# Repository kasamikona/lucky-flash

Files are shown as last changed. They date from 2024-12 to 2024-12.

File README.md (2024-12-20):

# Lucky Guitar Flashcart
A custom flashcart for the Lucky Group electronic guitar toy (らっき組 ギター) RK-001, made by People Co., Ltd.  

## What's it for?
The guitar toy, which I will call the Lucky Guitar from here onwards, has multiple play modes.
One of these modes uses ROM cartridges containing songs which you can play along with.
The songs are stored as MIDI files containing chord information.  

There were 14 main cartridges made, focusing on certain genres or artists,
and an additional "demo" cartridge containing a compilation of songs from the others.
The Lucky Guitar came with 2 or 3 random cartridges in the box, though additional ones could be purchased.
As it was a relatively obscure device, the cartridges are quite rare and it is very hard to collect them all.  

To allow the Lucky Guitar to be enjoyed to its fullest, I have developed a flash cart based heavily on the original cartridge design.
It supports playing ROM dumps of existing cartridges, as well as custom ROMs made from your own suitable MIDI files.
The latest version supports up to 8 different ROMs on one cartridge, with DIP switches to select them.  

Due to their small size, the flash carts contain no active logic and must be programmed externally.
Currently this is done through a custom adapter stackup for the TL866 (aka "MiniPro") Universal Programmer.
The stackup consists of a SN001-1 aka TSOP48 V3 base board from XinGong Tech, and the custom cartridge interface from here.
This adapter stack also allows dumping ROMs from the original cartridges after some modifications.  

## Contents
The main files you will want for making and using the flash cart are:
- **CartFlashMulti**: the latest multi-bank flash cart with DIP switches, intended for use with the custom shell. Gerber files coming soon.
- **LuckyCartInterface-TL866**: flash programmer interface for the TL866 and SN001-1. Gerber files coming soon.
- **CartShell.scad**: custom cart shell for the multi-bank flash cart, designed for SLA 3D printing. Render the main and cover parts separately. STL files coming soon.
- **CartParts.kicad_sym / CartParts.pretty**: custom KiCad parts shared between all PCBs.

The repo contains these additional files:
- **CartReplica**: a copy of the original cart PCB for research and analysis.
- **CartFlashSingle**: a flash cart based on the original carts, with minimal changes to support externally programming a flash chip. This can fit in an original shell.
- **DIP48-SN001**: a helper board that theoretically allows the cart interface to be used on other programming devices with 48-pin sockets.

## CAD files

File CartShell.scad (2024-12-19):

// Output settings
render_main = true;
render_cover = false;
prerender = true;
preview_print = true;

// Enhancements
enh_dipswitch = true;
enh_noholes = false;
enh_snapfit = true;
enh_post_supports = true;
enh_pegs_to_slots = true;
enh_label_top = true;

// Main dimensions
main_xsize = 68.8;
main_xslant = 0.3/20;
wall_xy = 1.5;
wall_z = 1.5;
wall_supp = 1.1;
wall_notch = 1.1;
curve_xc = 40.5;
curve_yc = -255;
curve_angle_start = 91;
curve_angle_range = 15.5;
profile_front = 46;
profile_handle_depth = profile_front-10;
profile_handle_slant = 0.12;
profile_handle_chamfer = 4.5;
main_height = 12.7;
handle_height = 15;

// Secondary dimensions
ridge_height = 1.5;
ridge_inset = 1.5;
label_height = 0.5;

// Screws & posts
screw_od = 2.0; //2.3
screwhead_od = 3.8;
screwpost_od = 4.0;
screw_shrink = 0.3;

// Clearances
clearance_lid = 0.3;
clearance_pcb = 0.2;
clearance_postxy = 0.2;
clearance_postz = 0.1;
clearance_screw = 0.1;
clearance_snap = 0.1;

// PCB parameters
pcb_thick = 1.2;
pcb_ypos = 0.5;
pcb_zpos = 5.7;
pcb_cardedge_width = 58;

// DIP switch dimensions
dip_n = 4;
dip_x = 23;
dip_y = 29;
dip_t = 3.6;
dip_angle = 90;
dip_w = 6.6;
dip_h = 2.54*dip_n + 1.2;
dip_rim_top = true;
dip_rim_bottom = false;
dip_rim_left = false;
dip_rim_right = true;

// Fixing positions
screws = [
    [-30,13.5], [30,13.5], [-30,32], [30,40]
];
snaps = [
    [-1, 10.5], [1, 10.5], [-1, 29], [1, 38]
];

// Calculated
detail = $preview ? 4 : 16;
below_pcb = pcb_zpos - clearance_pcb;
above_pcb = pcb_zpos + pcb_thick + clearance_pcb;
cover_zsize = below_pcb;
max_height = handle_height+ridge_height+1;
print_spacing = 5;
epsilon = 0.05;
screwhole_id = screwhead_od + 2*clearance_screw;

// Viewport centering
//$vpt = [0, profile_front/2, max_height/2];

module profile_curve(detail) {
    fnc = round(detail * 360 / curve_angle_range);
    translate([curve_xc,curve_yc,0])
    rotate([0,0,curve_angle_start])
    rotate_extrude(angle=curve_angle_range,
        convexity=5,$fn=fnc)
    translate([-curve_yc,0])
    children();
}

module main_profile(pocket, detail) {
    inset_xy = pocket ? wall_xy : 0;
    inset_z = pocket ? wall_z : 0;
    fdepth = profile_front-inset_xy;
    fslant = profile_handle_slant;
    tdepth = profile_handle_depth+inset_xy;
    fheight = handle_height-inset_z;
    theight = main_height-inset_z
        - (pocket ? label_height : 0);
    fcham = profile_handle_chamfer
        - max(inset_xy, inset_z);
    union() {
        hull() {
            polygon([
                [tdepth, 0], [fdepth, 0],
                [tdepth, fheight]
            ]);
            ch = fheight-fcham;
            sl = fslant*ch;
            translate([fdepth-sl-fcham, ch])
            intersection() {
                circle(r=fcham, $fn=detail*4);
                square(fcham+1);
            }
        }
        polygon([
            [0, 0], [tdepth+1, 0], 
            [tdepth+1, theight],
            [0, theight]
        ]);
    }
}

module side_profile(pocket, detail) {
    r1 = 1;
    h1 = main_height;
    h2 = handle_height;
    d1 = profile_front;
    slot_depth = 8;
    back = pocket ? slot_depth-epsilon : r1+1;
    union() {
        if(!pocket) hull() {
            polygon([
                [0, 0], [r1+2, 0],
                [r1+2, h1]
            ]);
            translate([r1, h1-r1])
            circle(r=r1, $fn=detail*4);
        }
        polygon([
            [back, 0], [d1, 0],
            [d1, h2], [back, h2]
        ]);
    }
}

module slant_profile(inset) {
    sp_height = max_height;
    x1 = main_xsize/2-inset;
    x2 = x1 - sp_height*main_xslant;
    polygon([
        [-x1, 0], [x1, 0],
        [x2, sp_height], [-x2, sp_height]
    ]);
}

module ridges(detail) {
    base = handle_height;
    sidegap = ridge_inset+(base*main_xslant);
    max_depth = profile_front;
    ridge_depth = 4;
    ridge_slant = 0.05;
    a = profile_handle_depth;
    b = a + ridge_depth*1/3;
    c = a + ridge_depth*2/3;
    d = a + ridge_depth;
    sl = ridge_slant * ridge_height;
    cx = main_xsize/2;
    intersection() {
        translate([-cx+sidegap, 0, 0])
        cube([main_xsize - 2*sidegap,
            max_depth, ridge_height+base]);
        profile_curve(detail*4){
            polygon([
                [a, 0],
                [b+sl, 0],
                [b+sl, base],
                [b, base+ridge_height],
                [a, base+ridge_height]
            ]);
            polygon([
                [c-sl, 0],
                [d, 0],
                [d, base+ridge_height],
                [c, base+ridge_height],
                [c-sl, base]
            ]);
        }
    }
}

module label(detail) {
    cheight = main_height;
    lheight = label_height;
    topgap = enh_label_top ? wall_xy : 0;
    bottomgap = wall_xy;
    sidegap = wall_xy+(cheight*main_xslant);
    cdepth = profile_handle_depth - topgap;
    lwidth = main_xsize-2*sidegap;
    cx = main_xsize/2;
    difference() {
        intersection() {
            profile_curve(detail*4) polygon([
                [0, cheight-lheight-1],
                [cdepth, cheight-lheight-1],
                [cdepth, cheight+1],
                [0, cheight+1]
            ]);
            translate([-cx+sidegap, bottomgap,
                cheight-lheight])
            cube([lwidth, cdepth+1,
                lheight+epsilon]);
        }
        if(enh_dipswitch) dip_hole(detail, true);
    }
}

module lock_notch(inset) {
    case_xsize = main_xsize/2-inset;
    xsize = 3;
    ysize = 8 + inset*1.41;
    zsize = main_height - wall_z;
    slant = 0.01 * zsize;
    ypos = 27.5-inset;
    translate([case_xsize,ypos,-epsilon])
    hull() {
        linear_extrude(epsilon)
        polygon([
            [-xsize, 0],
            [epsilon, 0],
            [epsilon, ysize+slant+epsilon],
            [-xsize, ysize+slant-xsize]
        ]);
        translate([0,0,zsize])
        linear_extrude(epsilon)
        polygon([
            [-xsize, 0],
            [epsilon, 0],
            [epsilon, ysize+epsilon],
            [-xsize, ysize-xsize]
        ]);
    }
}

module slot_cutout() {
    inset = wall_xy;
    height = main_height-wall_z;
    cutout_width = main_xsize-2*inset;
    depth = 8+epsilon;
    cx = main_xsize/2;
    translate([inset-cx,-epsilon,-epsilon])
    cube([cutout_width, depth+epsilon, height]);
}

module dip_hole(detail, negative) {
    max_side = 100;
    rim_radius = 1.0;
    c_w = dip_w +
        (negative ? rim_radius*2 : 0);
    c_h = dip_h +
        (negative ? rim_radius*2 : 0);
    corner_radius = negative ? rim_radius : 0.25;
    shrink = negative ? 0 : corner_radius*2*0.5;
    fn = detail * (negative ? 4 : 2);
    translate([dip_x, dip_y+pcb_ypos])
    minkowski() {
        rotate([0, 0, dip_angle])
        minkowski() {
            translate([0, 0, max_height/2])
            cube([c_w-shrink, c_h-shrink,
                max_height], true);
            if(corner_radius > 0)
            cylinder(r=corner_radius, h=1, $fn=fn);
        }
        if(negative) {
            rexx = dip_rim_left ? -max_side : 0;
            rexy = dip_rim_bottom ? -max_side : 0;
            rexw = (dip_rim_left ? max_side : 0)
                + (dip_rim_right ? max_side : 0)
                + 0.001;
            rexh = (dip_rim_top ? max_side : 0)
                + (dip_rim_bottom ? max_side : 0)
                + 0.001;
            translate([rexx, rexy, 0])
            cube([rexw, rexh, 1]);
        }
    }
}

module snapfit(indent) {
    extra_inset = indent ? clearance_snap : 0;
    snap_xsize = clearance_lid + 0.5;
    snap_zsizet = snap_xsize;
    snap_zsizeb = 1.5;
    snap_zpos = 2.0;
    snap_ysize = 2.0 + (indent ? 2*clearance_lid : 0);
    snap_inset = wall_xy + extra_inset;
    epsilon = 0.01;
    zeb = epsilon * snap_zsizeb/snap_xsize;
    zet = epsilon * snap_zsizet/snap_xsize;
    for(snap = snaps) {
        sxsign = -sign(snap[0]);
        sx = -main_xsize/2 + snap_inset;
        sy = snap[1];
        translate([sx*sxsign, sy, snap_zpos])
        rotate([90,0,0])
        linear_extrude(snap_ysize,
            center=true)
        polygon([
            [-epsilon*sxsign, -snap_zsizeb-zeb],
            [snap_xsize*sxsign, 0],
            [-epsilon*sxsign, snap_zsizet+zet]
        ]);
    }
}
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

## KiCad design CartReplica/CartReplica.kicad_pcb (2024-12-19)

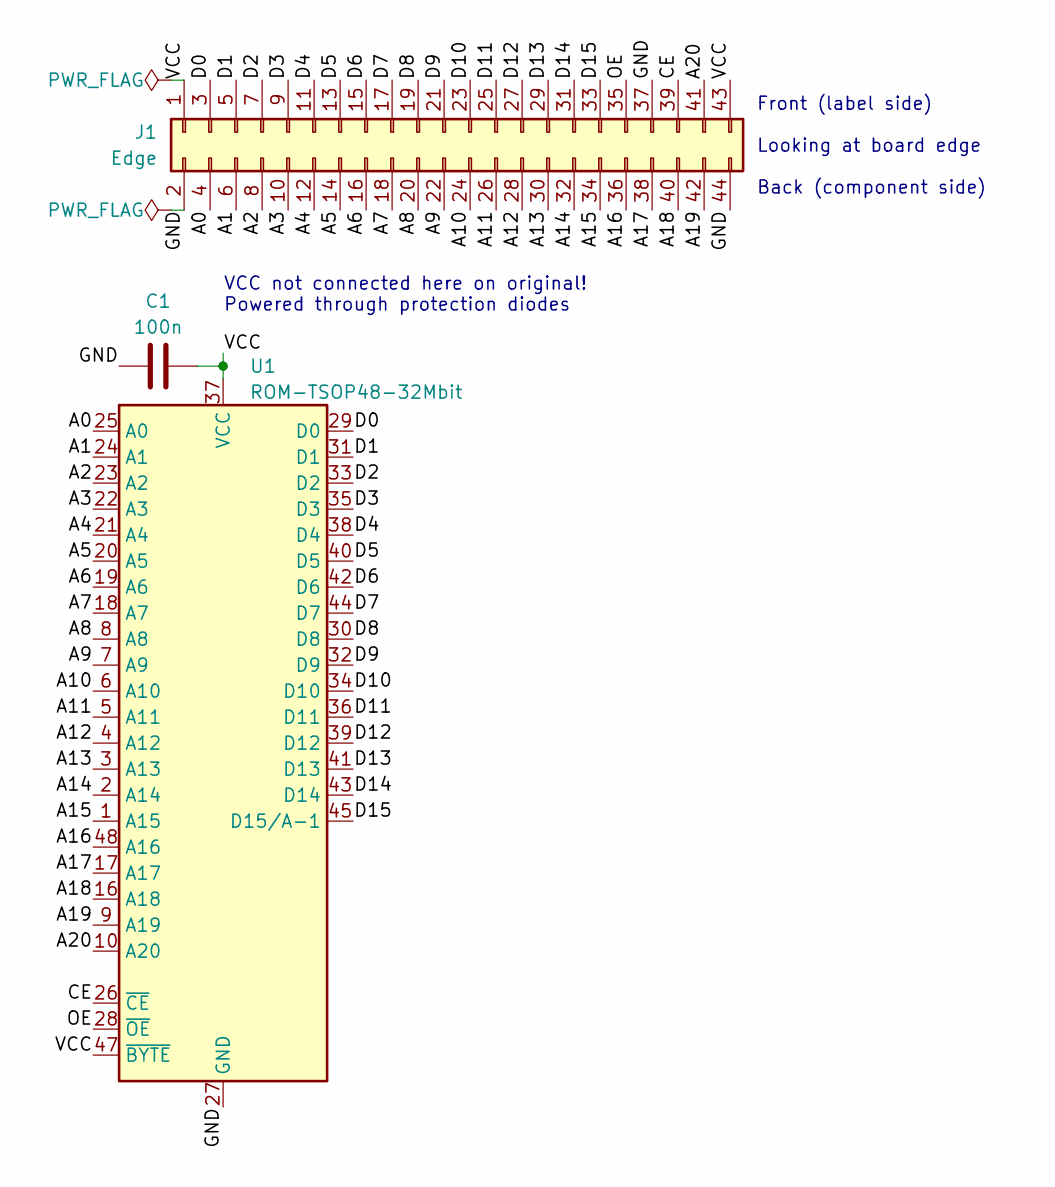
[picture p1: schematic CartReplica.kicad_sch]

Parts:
C1: 100n; C_0603_1608Metric_Pad1.08x0.95mm_HandSolder
J1: Edge; LuckyCartEdge
U1: ROM-TSOP48-32Mbit; TSOP-I-48_18.4x12mm_P0.5mm

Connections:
/A0: J1.4, U1.25 (A0)
/A1: J1.6, U1.24 (A1)
/A2: J1.8, U1.23 (A2)
/A3: J1.10, U1.22 (A3)
/A4: J1.12, U1.21 (A4)
/A5: J1.14, U1.20 (A5)
/A6: J1.16, U1.19 (A6)
/A7: J1.18, U1.18 (A7)
/A8: J1.20, U1.8 (A8)
/A9: J1.22, U1.7 (A9)
/A10: J1.24, U1.6 (A10)
/A11: J1.26, U1.5 (A11)
/A12: J1.28, U1.4 (A12)
/A13: J1.30, U1.3 (A13)
/A14: J1.32, U1.2 (A14)
/A15: J1.34, U1.1 (A15)
/A16: J1.36, U1.48 (A16)
/A17: J1.38, U1.17 (A17)
/A18: J1.40, U1.16 (A18)
/A19: J1.42, U1.9 (A19)
/A20: J1.41, U1.10 (A20)
/CE: J1.39, U1.26 (~CE)
/D0: J1.3, U1.29 (D0)
/D1: J1.5, U1.31 (D1)
/D2: J1.7, U1.33 (D2)
/D3: J1.9, U1.35 (D3)
/D4: J1.11, U1.38 (D4)
/D5: J1.13, U1.40 (D5)
/D6: J1.15, U1.42 (D6)
/D7: J1.17, U1.44 (D7)
/D8: J1.19, U1.30 (D8)
/D9: J1.21, U1.32 (D9)
/D10: J1.23, U1.34 (D10)
/D11: J1.25, U1.36 (D11)
/D12: J1.27, U1.39 (D12)
/D13: J1.29, U1.41 (D13)
/D14: J1.31, U1.43 (D14)
/D15: J1.33, U1.45 (D15/A-1)
/OE: J1.35, U1.28 (~OE)
/VCC: C1.1, J1.1, J1.43, U1.37 (VCC), U1.47 (~BYTE)
GND: C1.2, J1.2, J1.37, J1.44, U1.27 (GND), U1.46 (GND)

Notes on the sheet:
VCC not connected here on original! Powered through protection diodes
Front (label side) Looking at board edge Back (component side)

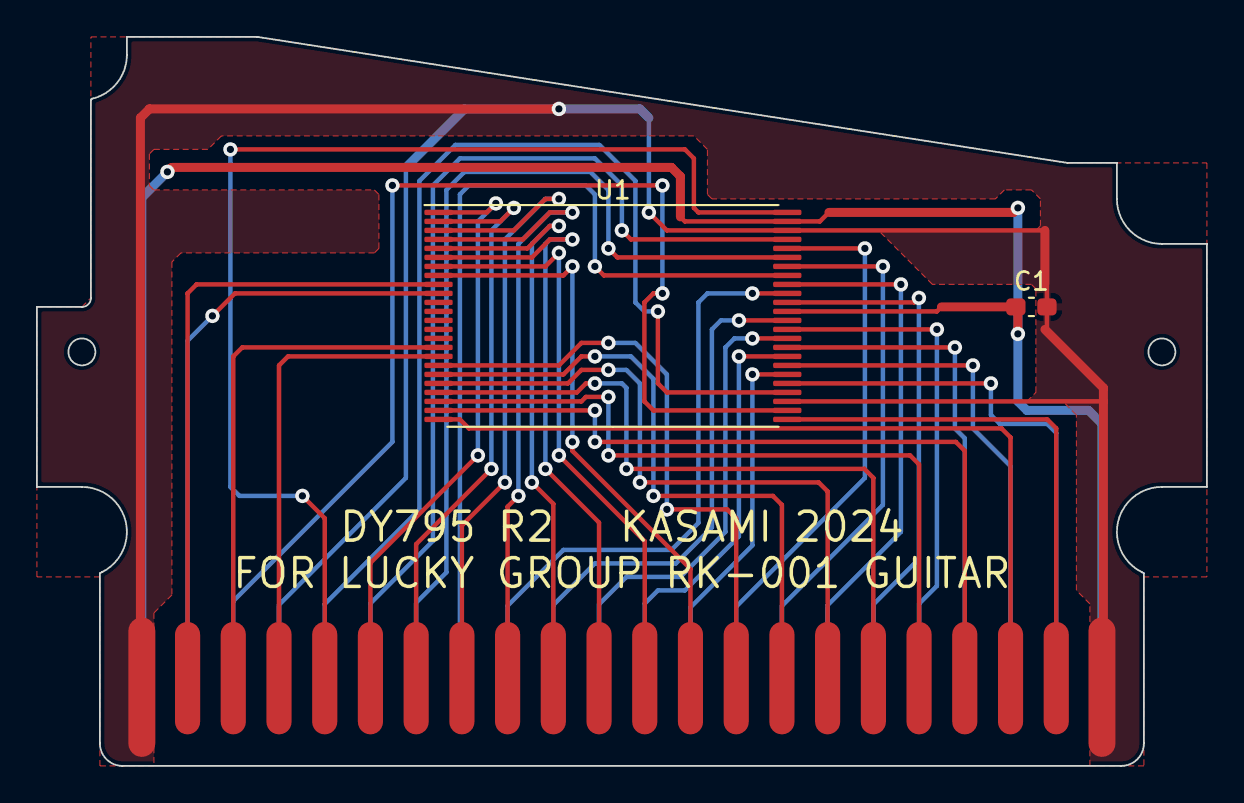
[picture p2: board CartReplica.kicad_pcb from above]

Board: 2 copper layers, 65.0 x 40.5 mm, 3 parts (1 on the bottom side), 41 nets.

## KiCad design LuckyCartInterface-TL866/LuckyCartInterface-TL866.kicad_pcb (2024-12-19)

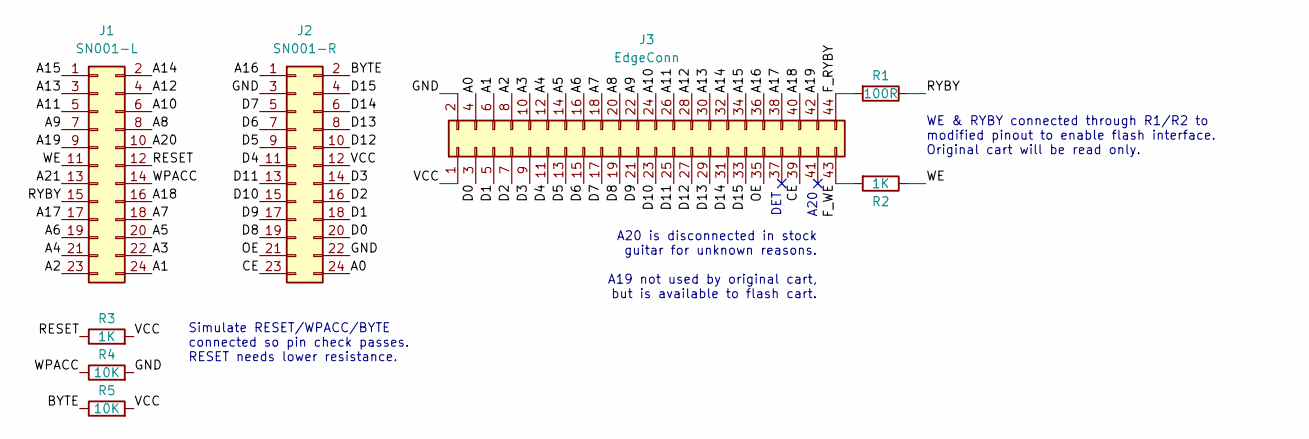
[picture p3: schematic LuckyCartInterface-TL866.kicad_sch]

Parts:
J1: SN001-L; PinSocket_2x12_P2.54mm_Vertical
J2: SN001-R; PinSocket_2x12_P2.54mm_Vertical
J3: EdgeConn; TE_Standard-Edge-II_44P
R1: 100R; R_0603_1608Metric_Pad0.98x0.95mm_HandSolder
R2, R3: 1K; R_0603_1608Metric_Pad0.98x0.95mm_HandSolder
R4, R5: 10K; R_0603_1608Metric_Pad0.98x0.95mm_HandSolder

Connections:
/A0: J2.24, J3.4
/A1: J1.24, J3.6
/A2: J1.23, J3.8
/A3: J1.22, J3.10
/A4: J1.21, J3.12
/A5: J1.20, J3.14
/A6: J1.19, J3.16
/A7: J1.18, J3.18
/A8: J1.8, J3.20
/A9: J1.7, J3.22
/A10: J1.6, J3.24
/A11: J1.5, J3.26
/A12: J1.4, J3.28
/A13: J1.3, J3.30
/A14: J1.2, J3.32
/A15: J1.1, J3.34
/A16: J2.1, J3.36
/A17: J1.17, J3.38
/A18: J1.16, J3.40
/A19: J1.9, J3.42
/A20: J1.10
/A21: J1.13
/BYTE: J2.2, R5.1
/CE: J2.23, J3.39
/D0: J2.20, J3.3
/D1: J2.18, J3.5
/D2: J2.16, J3.7
/D3: J2.14, J3.9
/D4: J2.11, J3.11
/D5: J2.9, J3.13
/D6: J2.7, J3.15
/D7: J2.5, J3.17
/D8: J2.19, J3.19
/D9: J2.17, J3.21
/D10: J2.15, J3.23
/D11: J2.13, J3.25
/D12: J2.10, J3.27
/D13: J2.8, J3.29
/D14: J2.6, J3.31
/D15: J2.4, J3.33
/F_RYBY: J3.44, R1.2
/F_WE: J3.43, R2.2
/GND: J2.3, J2.22, J3.2, R4.2
/OE: J2.21, J3.35
/RESET: J1.12, R3.1
/RYBY: J1.15, R1.1
/VCC: J2.12, J3.1, R3.2, R5.2
/WE: J1.11, R2.1
/WPACC: J1.14, R4.1

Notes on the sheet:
WE & RYBY connected through R1/R2 to modified pinout to enable flash interface. Original cart will be read only.
DET
A20 is disconnected in stock guitar for unknown reasons. A19 not used by original cart, but is available to flash cart.
Simulate RESET/WPACC/BYTE connected so pin check passes. RESET needs lower resistance.
A20

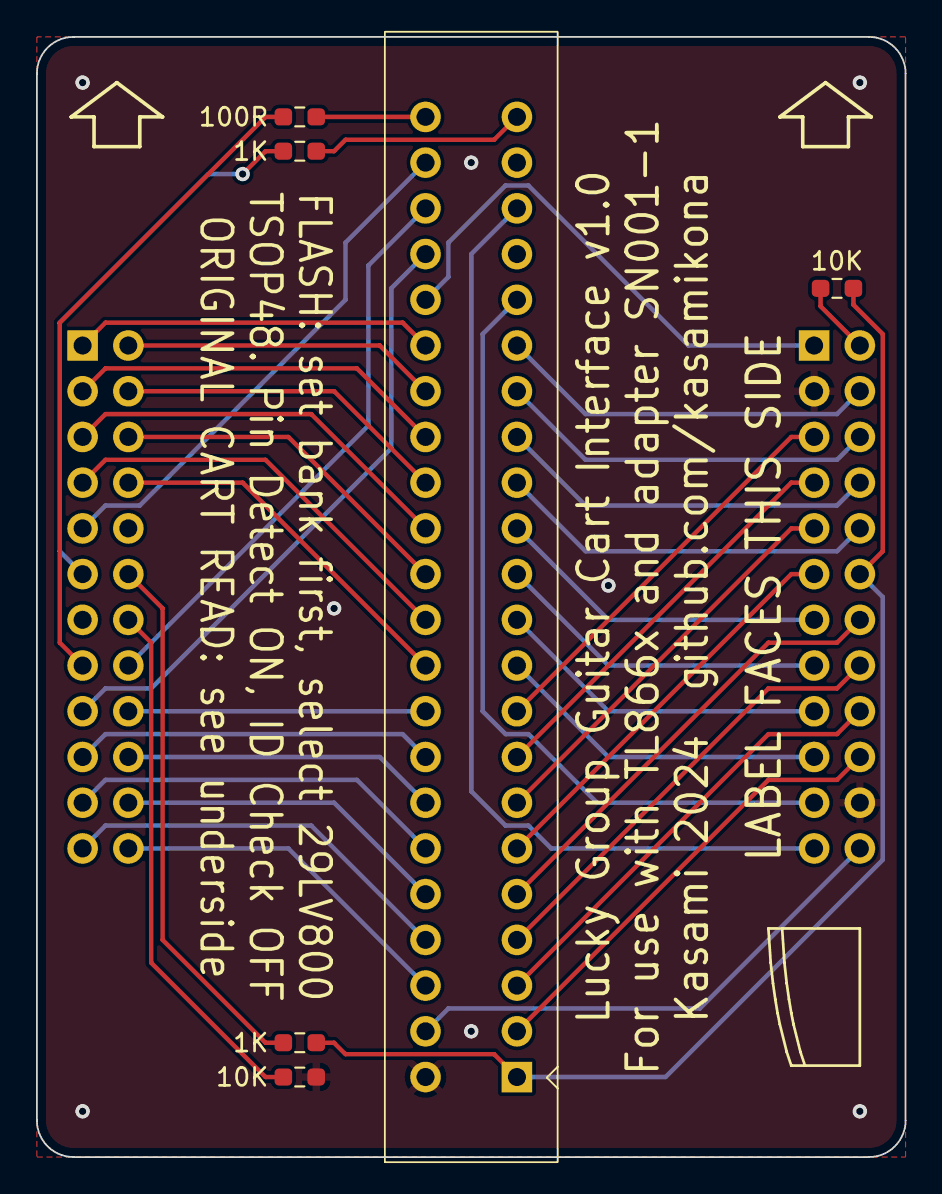
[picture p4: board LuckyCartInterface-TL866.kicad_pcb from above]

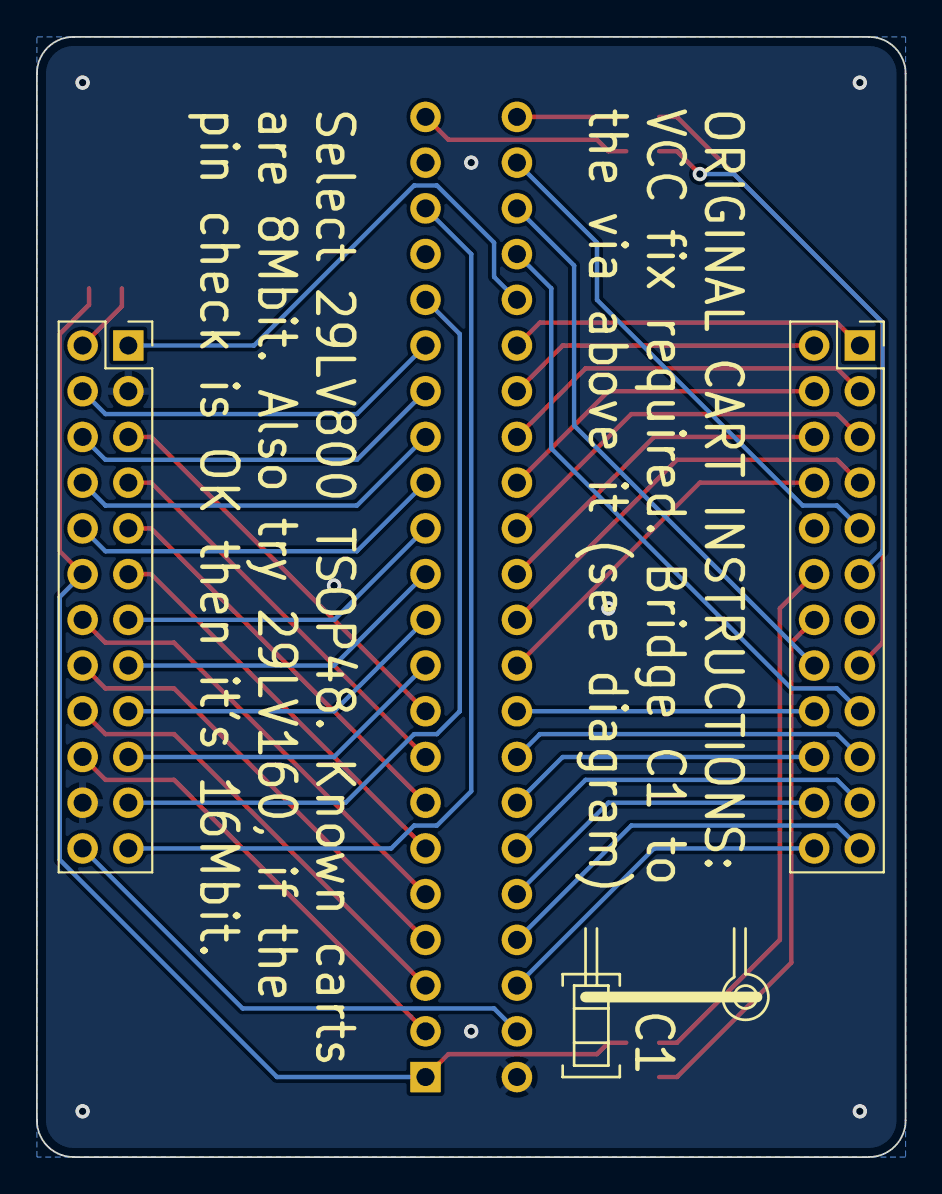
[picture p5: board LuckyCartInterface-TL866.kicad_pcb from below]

Board: 2 copper layers, 48.3 x 62.2 mm, 8 parts (2 on the bottom side), 47 nets.

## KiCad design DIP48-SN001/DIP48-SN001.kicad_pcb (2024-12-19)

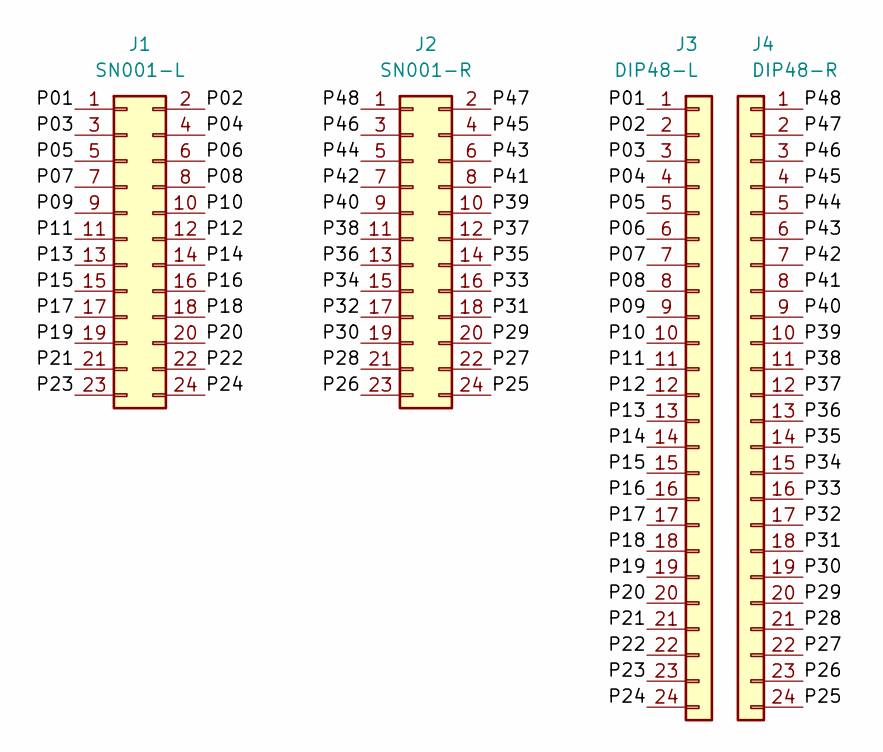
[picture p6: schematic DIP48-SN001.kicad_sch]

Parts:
J1: SN001-L; PinHeader_2x12_P2.54mm_Vertical
J2: SN001-R; PinHeader_2x12_P2.54mm_Vertical
J3: DIP48-L; PinHeader_1x24_P2.54mm_Vertical
J4: DIP48-R; PinHeader_1x24_P2.54mm_Vertical

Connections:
/P01: J1.1, J3.1
/P02: J1.2, J3.2
/P03: J1.3, J3.3
/P04: J1.4, J3.4
/P05: J1.5, J3.5
/P06: J1.6, J3.6
/P07: J1.7, J3.7
/P08: J1.8, J3.8
/P09: J1.9, J3.9
/P10: J1.10, J3.10
/P11: J1.11, J3.11
/P12: J1.12, J3.12
/P13: J1.13, J3.13
/P14: J1.14, J3.14
/P15: J1.15, J3.15
/P16: J1.16, J3.16
/P17: J1.17, J3.17
/P18: J1.18, J3.18
/P19: J1.19, J3.19
/P20: J1.20, J3.20
/P21: J1.21, J3.21
/P22: J1.22, J3.22
/P23: J1.23, J3.23
/P24: J1.24, J3.24
/P25: J2.24, J4.24
/P26: J2.23, J4.23
/P27: J2.22, J4.22
/P28: J2.21, J4.21
/P29: J2.20, J4.20
/P30: J2.19, J4.19
/P31: J2.18, J4.18
/P32: J2.17, J4.17
/P33: J2.16, J4.16
/P34: J2.15, J4.15
/P35: J2.14, J4.14
/P36: J2.13, J4.13
/P37: J2.12, J4.12
/P38: J2.11, J4.11
/P39: J2.10, J4.10
/P40: J2.9, J4.9
/P41: J2.8, J4.8
/P42: J2.7, J4.7
/P43: J2.6, J4.6
/P44: J2.5, J4.5
/P45: J2.4, J4.4
/P46: J2.3, J4.3
/P47: J2.2, J4.2
/P48: J2.1, J4.1

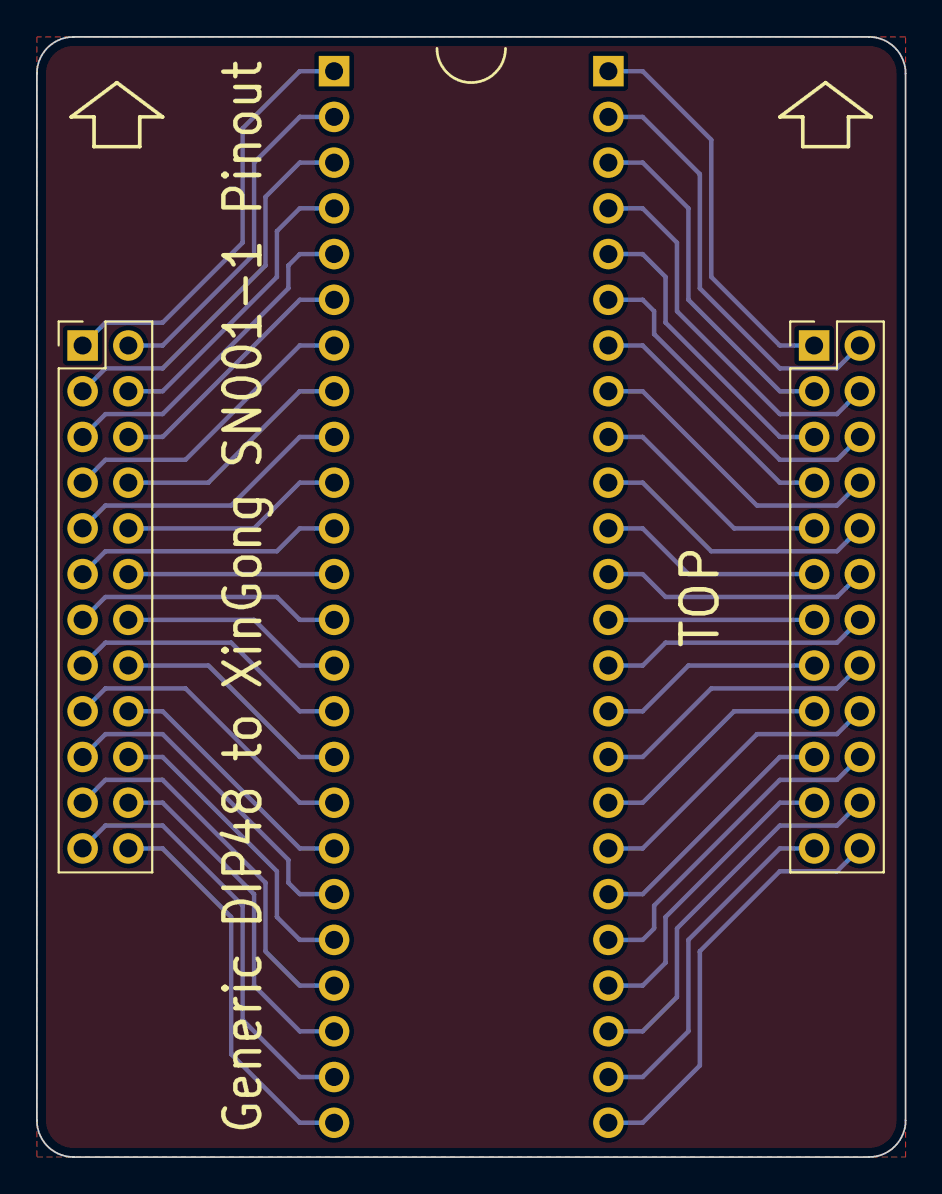
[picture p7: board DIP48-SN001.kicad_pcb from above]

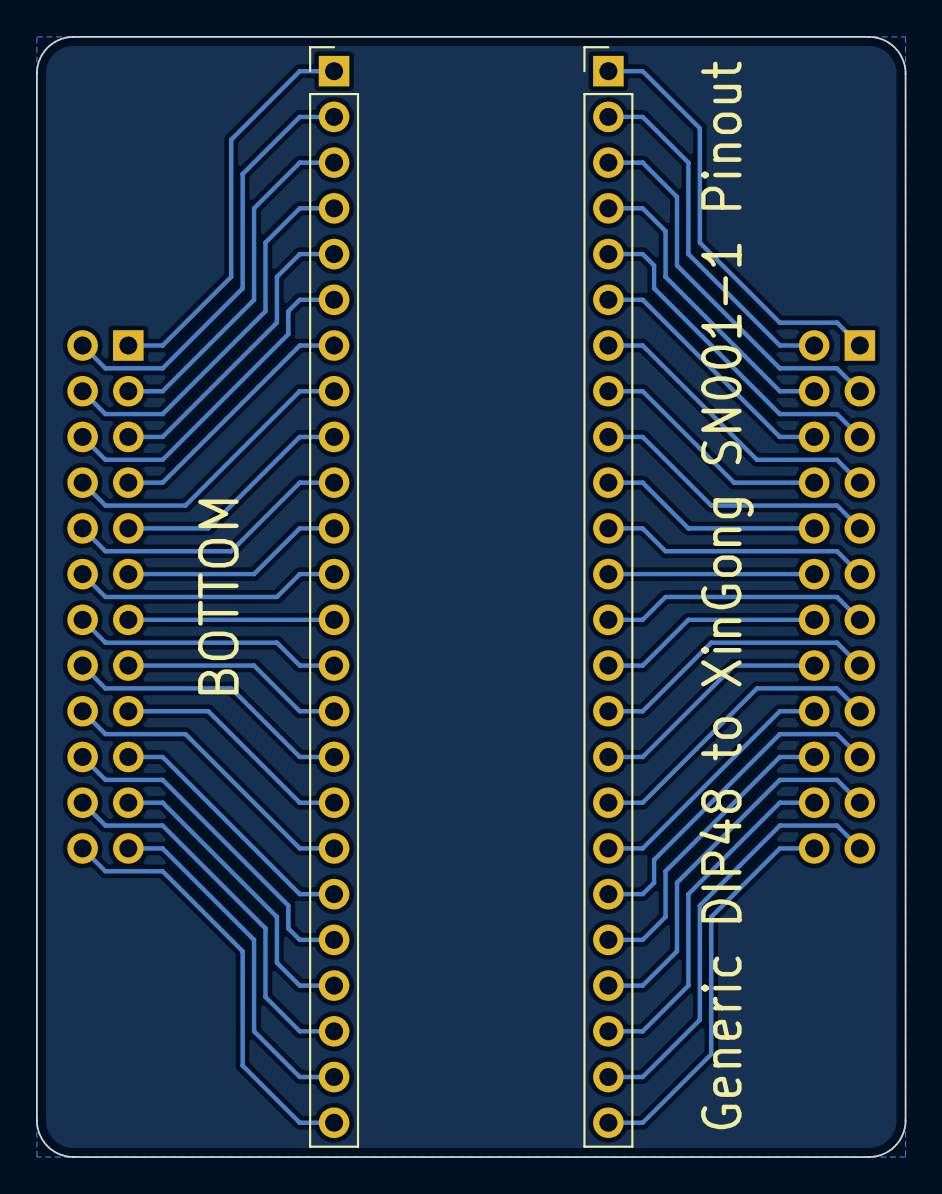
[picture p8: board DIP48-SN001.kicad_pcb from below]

Board: 2 copper layers, 48.3 x 62.2 mm, 4 parts (2 on the bottom side), 48 nets.
